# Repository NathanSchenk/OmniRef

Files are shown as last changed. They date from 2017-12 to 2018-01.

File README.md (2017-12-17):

# OmniRef
A universal voltage reference

<br />This work is licensed under a <a rel="license" href="http://creativecommons.org/licenses/by-sa/4.0/">Creative Commons Attribution-ShareAlike 4.0 International License</a>.

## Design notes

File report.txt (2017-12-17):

Plot file 'Z:\Projects\OmniRef\Gerbers\OmniRef-F.Cu.gbr' created.
Plot file 'Z:\Projects\OmniRef\Gerbers\OmniRef-B.Cu.gbr' created.
Plot file 'Z:\Projects\OmniRef\Gerbers\OmniRef-B.Adhes.gbr' created.
Plot file 'Z:\Projects\OmniRef\Gerbers\OmniRef-F.Adhes.gbr' created.
Plot file 'Z:\Projects\OmniRef\Gerbers\OmniRef-B.Paste.gbr' created.
Plot file 'Z:\Projects\OmniRef\Gerbers\OmniRef-F.Paste.gbr' created.
Plot file 'Z:\Projects\OmniRef\Gerbers\OmniRef-B.SilkS.gbr' created.
Plot file 'Z:\Projects\OmniRef\Gerbers\OmniRef-F.SilkS.gbr' created.
Plot file 'Z:\Projects\OmniRef\Gerbers\OmniRef-B.Mask.gbr' created.
Plot file 'Z:\Projects\OmniRef\Gerbers\OmniRef-F.Mask.gbr' created.
Plot file 'Z:\Projects\OmniRef\Gerbers\OmniRef-Cmts.User.gbr' created.
Plot file 'Z:\Projects\OmniRef\Gerbers\OmniRef-Edge.Cuts.gbr' created.
Plot file 'Z:\Projects\OmniRef\Gerbers\OmniRef-Margin.gbr' created.
Plot file 'Z:\Projects\OmniRef\Gerbers\OmniRef-B.CrtYd.gbr' created.
Plot file 'Z:\Projects\OmniRef\Gerbers\OmniRef-F.CrtYd.gbr' created.
Plot file 'Z:\Projects\OmniRef\Gerbers\OmniRef-B.Fab.gbr' created.
Plot file 'Z:\Projects\OmniRef\Gerbers\OmniRef-F.Fab.gbr' created.

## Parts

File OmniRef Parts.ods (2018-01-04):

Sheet: Master Parts List
Reference Designator | Description | Manufacturer | Manufacturer Part | Digi-Key | Cost | Comments
Case | Enclosure | Budd | CU1941 | 377-2068-ND (https://www.digikey.com/product-detail/en/bud-industries/CU-1941/377-2068-ND/439228) | $2.10
BT1 | Battery Snap | Keystone | 81-4 | 36-81-4-ND (https://www.digikey.com/product-detail/en/keystone-electronics/81-4/36-81-4-ND/303952) | $0.71
J1+ | Red Banana Jack | Mueller | BU-00233-2 | 314-1358-ND (https://www.digikey.com/product-detail/en/mueller-electric-co/BU-00233-2/314-1358-ND/2688274) | $1.40 | Gold plated versions available from parts express (https://www.parts-express.com/gold-plated-banana-jack-pair--091-1160)
J1- | Black Banana Jack | Mueller | BU-00233-0 | 314-1357-ND (https://www.digikey.com/product-detail/en/mueller-electric-co/BU-00233-0/314-1357-ND/2688273) | $1.40
J2+ | Red Banana Jack | Mueller | BU-00233-2 | 314-1358-ND (https://www.digikey.com/product-detail/en/mueller-electric-co/BU-00233-2/314-1358-ND/2688274) | $1.40
J2- | Black Banana Jack | Mueller | BU-00233-0 | 314-1357-ND (https://www.digikey.com/product-detail/en/mueller-electric-co/BU-00233-0/314-1357-ND/2688273) | $1.40
SW1 | DPDT Switch | C&K | L202011MS02Q | CKC5100-ND (https://www.digikey.com/product-detail/en/c-k/L202011MS02Q/CKC5100-ND/13853) | $2.94 | Used for battery/external power selection. Also functions as on/off if only one power source is available.
U1 | Series Voltage Reference |  |  |  |  | See "References" page for specific parts
U2 | LDO Regulator | On Semiconductor | LP2951ACDR2G | LP2951ACDR2GOSCT-ND (https://www.digikey.com/product-detail/en/on-semiconductor/LP2951ACDR2G/LP2951ACDR2GOSCT-ND/917952) | $0.65 | LP2951 is the most popular compatable part number, but others will fit. Be sure to get the adjustable version. The A suffix has better regulation.
U3 | Series Voltage Reference |  |  |  |  | Placeholder for DIP footprint reference.
U4 | AP3015 Boost Converter | Diodes Incorporated | AP3015KTR-G1 | AP3015KTR-G1DICT-ND (https://www.digikey.com/product-detail/en/diodes-incorporated/AP3015KTR-G1/AP3015KTR-G1DICT-ND/4505299) | $0.73 | Boost Converter. The AP3015AKTR-G1 is a lower current version that may be a better choice.
Q1 | PNP Transistor | Nexperia | PMBT3906.215 | 1727-2960-1-ND (https://www.digikey.com/product-detail/en/nexperia-usa-inc/PMBT3906215/1727-2960-1-ND/763516) | $0.10 | Drives the "Low Battery" LED
D1 | 1A General Purpose Diode | SMC Diode Solutions | S1MTR | 1655-1506-1-ND (https://www.digikey.com/product-detail/en/smc-diode-solutions/S1MTR/1655-1506-1-ND/6022951) | $0.14 | Input rectifier to protect against reverse polarity connection of external power supply.
D2 | 1A General Purpose Diode | SMC Diode Solutions | S1MTR | 1655-1506-1-ND (https://www.digikey.com/product-detail/en/smc-diode-solutions/S1MTR/1655-1506-1-ND/6022951) | $0.14 | Protects reference IC against being driven by the output terminals.
D3 | 1A General Purpose Diode | SMC Diode Solutions | S1MTR | 1655-1506-1-ND (https://www.digikey.com/product-detail/en/smc-diode-solutions/S1MTR/1655-1506-1-ND/6022951) | $0.14 | Protects first regulator against being driven by the output terminals
D5 | Yellow LED | Kingbright | APTR3216SYCK | 754-1174-1-ND (https://www.digikey.com/product-detail/en/kingbright/APTR3216SYCK/754-1174-1-ND/1747891) | $0.48 | "Low Battery" indication
D6 | 12V Zener Diode | On Semiconductor | 1SMA5927BT3G | 1SMA5927BT3GOSCT-ND (https://www.digikey.com/product-detail/en/on-semiconductor/1SMA5927BT3G/1SMA5927BT3GOSCT-ND/917680) | $0.38 | Protects the reference IC from external voltages applied to the output terminals.
D7 | Green LED | Kingbright | APTR3216CGCK | 754-1167-1-ND (https://www.digikey.com/product-detail/en/kingbright/APTR3216CGCK/754-1167-1-ND/1747884) | $0.39 | "Power On" indication
D8 | 1A Schottky Diode | On Semiconductor | SS14 | SS14CT-ND (https://www.digikey.com/product-detail/en/on-semiconductor/SS14/SS14CT-ND/965729) | $0.41 | Series diode for boost converter
D9 | 1A General Purpose Diode | SMC Diode Solutions | S1MTR | 1655-1506-1-ND (https://www.digikey.com/product-detail/en/smc-diode-solutions/S1MTR/1655-1506-1-ND/6022951) | $0.14 | Protects against reverse polarity from the battery terminals
C1 | 1uF 35v X7R 0805 Ceramic Capacitor | Taiyo Yuden | GMK212B7105KG-T | 587-1438-1-ND (https://www.digikey.com/product-detail/en/taiyo-yuden/GMK212B7105KG-T/587-1438-1-ND/1004069) | $0.14
C2 | 10uF 35v X5R 0805 Ceramic Capacitor | Murata | GRM21BR6YA106ME43L | 490-10515-1-ND (https://www.digikey.com/product-detail/en/murata-electronics-north-america/GRM21BR6YA106ME43L/490-10515-1-ND/5026446) | $0.26
C3 | 1uF 35v X7R 0805 Ceramic Capacitor | Taiyo Yuden | GMK212B7105KG-T | 587-1438-1-ND (https://www.digikey.com/product-detail/en/taiyo-yuden/GMK212B7105KG-T/587-1438-1-ND/1004069) | $0.14 | This part improves stability and reduces noise on the linear regulator.
C4 | 1uF 35v X7R 0805 Ceramic Capacitor | Taiyo Yuden | GMK212B7105KG-T | 587-1438-1-ND (https://www.digikey.com/product-detail/en/taiyo-yuden/GMK212B7105KG-T/587-1438-1-ND/1004069) | $0.14
C5 | 1uF 35v X7R 0805 Ceramic Capacitor | Taiyo Yuden | GMK212B7105KG-T | 587-1438-1-ND (https://www.digikey.com/product-detail/en/taiyo-yuden/GMK212B7105KG-T/587-1438-1-ND/1004069) | $0.14
C6 | 10uF 35v X5R 0805 Ceramic Capacitor | Murata | GRM21BR6YA106ME43L | 490-10515-1-ND (https://www.digikey.com/product-detail/en/murata-electronics-north-america/GRM21BR6YA106ME43L/490-10515-1-ND/5026446) | $0.26 | Main bypass capacitor for the linear regulator
C7 | 10uF 35v X5R 0805 Ceramic Capacitor | Murata | GRM21BR6YA106ME43L | 490-10515-1-ND (https://www.digikey.com/product-detail/en/murata-electronics-north-america/GRM21BR6YA106ME43L/490-10515-1-ND/5026446) | $0.26
C8 | 10uF 35v X5R 0805 Ceramic Capacitor | Murata | GRM21BR6YA106ME43L | 490-10515-1-ND (https://www.digikey.com/product-detail/en/murata-electronics-north-america/GRM21BR6YA106ME43L/490-10515-1-ND/5026446) | $0.26
C9 | 10uF 6032 25V Tantalum Capacitor |  | T491C106K035AT | 399-8333-1-ND (https://www.digikey.com/product-detail/en/kemet/T491C106K035AT/399-8333-1-ND/3472056) | $0.62
C10 | 1uF 35v X7R 0805 Ceramic Capacitor | Taiyo Yuden | GMK212B7105KG-T | 587-1438-1-ND (https://www.digikey.com/product-detail/en/taiyo-yuden/GMK212B7105KG-T/587-1438-1-ND/1004069) | $0.14 | Reduces noise on certain Maxim references
C11 | 10uF 35v X5R 0805 Ceramic Capacitor | Murata | GRM21BR6YA106ME43L | 490-10515-1-ND (https://www.digikey.com/product-detail/en/murata-electronics-north-america/GRM21BR6YA106ME43L/490-10515-1-ND/5026446) | $0.26 | Input bypass capacitor for the boost converter
C12 | 10pF 50V NP0 Ceramic Capacitor |  |  |  | $0.10 | Stabilizing capacitor for the boost converter
C13 | 10uF 35v X5R 0805 Ceramic Capacitor | Murata | GRM21BR6YA106ME43L | 490-10515-1-ND (https://www.digikey.com/product-detail/en/murata-electronics-north-america/GRM21BR6YA106ME43L/490-10515-1-ND/5026446) | $0.26 | Output bypass capacitor for the boost converter
RV1 | 10K SMD Trimmer 3324W | Bourns | 3224W-1-103E | 3224W-103ECT-ND (https://www.digikey.com/product-detail/en/bourns-inc/3224W-1-103E/3224W-103ECT-ND/225672) | $4.92 | Only used for references with trim terminal. See "References" page for specific parts.
R1 | 0805 Resistor |  |  |  | $0.10 | Part of linear regulator voltage setting network. See "Linear Regulator" page for details
R2 | High Stability 0805 Resistor |  |  |  | $0.10 | Only used for references with trim terminal. This needs to be a high stability part. See "References" page for details.
R3 | 0805 Resistor |  |  |  | $0.10 | Part of linear regulator voltage setting network. See "Linear Regulator" page for details
R4 | 1 Ohm 0805 Resistor |  |  |  | $0.10 | This increases the ESR of the bypass capacitor on the linear regulator. Helps keep LDO from oscillating.
R5 | 100K 0805 Resistor |  |  |  | $0.10 | Bias resistor for Q1. 100K is the minimum value allowed by the LDO error terminal.
R6 | 1 Ohm 0805 Resistor |  |  |  | $0.10 | This increases the ESR of the bypass capacitor on the voltage reference. Helps prevent oscillatons.
R7 | 1K 0805 Resistor |  |  |  | $0.10 | Dropping resistor for "Low Battery" LED
R8 | 10K 0805 Resistor |  |  |  | $0.10 | Output resistor. Used to keep the reference IC biased in quadrant I. Not necessary if RV1 is used.
R9 | 0 Ohm 0805 Resistor |  |  |  | $0.10 | Only used for certain references. See "References" page to determine if needed.
R10 | 1K 0805 Resistor |  |  |  | $0.10 | Dropping resistor for "Power On" LED
R11 | 0 Ohm 0805 Resistor |  |  |  | $0.10 | Jumper to be used if the boost converter is not used.
R12 | 1M 0805 Resistor |  |  |  | $0.10 | Voltage setting resistor for the boost converter
R13 | 82K 0805 Resistor |  |  |  | $0.10 | Voltage setting resistor for the boost converter
R14 | High Stability 0805 Resistor |  |  |  | $0.10 | Used only for references with the "trim" terminal. "Expands the scale" of RV1
R15 | High Stability 0805 Resistor |  |  |  | $0.10 | Used only for references with the "trim" terminal. "Expands the scale" of RV1
L1 | 10uH Inductor | Taiyo Yuden | NR6028T100M | 587-2102-1-ND (https://www.digikey.com/product-detail/en/taiyo-yuden/NR6028T100M/587-2102-1-ND/1866242) | $0.32 | Inductor for the boost converter

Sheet: Linear Regulator
Primary Voltage Regulators:
SOIC Pinout | LP2954 | LP4951C | LP2951 | NCV2951
1 | OUT | OUTPUT | OUTPUT | OUTPUT
2 | SENSE | SENSE | SENSE | SENSE
3 | /SHUTDOWN | SHUTDOWN | SHUTDOWN | SHUTDOWN
4 | GROUND | GROUND | GND | GND
5 | /ERROR | /ERROR | /ERROR | /ERROR
6 | 5V TAP | V TAP | V TAP | V TAP
7 | FEEDBACK | FEEDBACK | FEEDBACK | FEEDBACK
8 | INPUT | INPUT | INPUT | INPUT
Resistor Selection: |  |  | LED | LED
Output Voltage | R3 | R1 | R7 | R10
13.58 | 100K | 10K | 3.9K | 3.9K
6.85 | 100K | 22K | 1.5K | 1.5K
4.98 | 100K | 33K | 1K | 1K

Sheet: Resistor Calc
AP3015 Resistor Calculator
R12 | 1000000 | Vout | 16.230
R13 | 82000
LP2951 Resistor Calculator
R3 | 100000 | Vout | 4.975
R1 | 33000
LED Resistor Calculator
R7 | 991.81 | I_LED | 0.003
R10 | 991.81 | I_LED | 0.003

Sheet: References
Part # | Package | Voltage | R9 | C10 | C4 | C5 | R2 | RV1 | R14 | R15
Texas Instruments
REF102CU | SO | 10.000 | No-Pop | No-Pop | 1uF | No-Pop | 1M | 20K | 1 | 1
REF102CP | PDIP | 10.000 | No-Pop | No-Pop | 1uF | No-Pop | 1M | 20K | 1 | 1
REF5010ID | SO | 10.000 | No-Pop | No-Pop | No-Pop | 1uF | 470K | 10K | 1 | 1
Analog Devices
ADR4550ARZ | SO | 5.000 | No-Pop | No-Pop | No-Pop | No-Pop | No-Pop | No-Pop | No-Pop | No-Pop
ADR4550BRZ | SO | 5.000 | No-Pop | No-Pop | No-Pop | No-Pop | No-Pop | No-Pop | No-Pop | No-Pop
ADR4530BRZ | SO | 3.000 | No-Pop | No-Pop | No-Pop | No-Pop | No-Pop | No-Pop | No-Pop | No-Pop
ADR4525BRZ | SO | 2.500 | No-Pop | No-Pop | No-Pop | No-Pop | No-Pop | No-Pop | No-Pop | No-Pop
AD587KRZ | SO | 10.000 | No-Pop | No-Pop | 1uF | No-Pop | 1 | 10K | 10K? | 10K?
AD587UQ | CDIP | 10.000 | No-Pop | No-Pop | 1uF | No-Pop | 1 | 10K | 10K? | 10K?
Maxim Integrated
MAX6325CPA | PDIP | 2.500 | No-Pop | 1uF | No-Pop | No-Pop | 1 | 10K | 1 | 1
MAX6325CSA | SO | 2.500 | No-Pop | 1uF | No-Pop | No-Pop | 1 | 10K | 1 | 1
MAX6325MJA | CDIP | 2.500 | No-Pop | 1uF | No-Pop | No-Pop | 1 | 10K | 1 | 1
MAX6341CPA | PDIP | 4.096 | No-Pop | 1uF | No-Pop | No-Pop | 1 | 10K | 1 | 1
MAX6341CSA | SO | 4.096 | No-Pop | 1uF | No-Pop | No-Pop | 1 | 10K | 1 | 1
MAX6341MJA | CDIP | 4.096 | No-Pop | 1uF | No-Pop | No-Pop | 1 | 10K | 1 | 1
MAX6350CPA | PDIP | 5.000 | No-Pop | 1uF | No-Pop | No-Pop | 1 | 10K | 1 | 1
MAX6350CSA | SO | 5.000 | No-Pop | 1uF | No-Pop | No-Pop | 1 | 10K | 1 | 1
MAX6350MJA | CDIP | 5.000 | No-Pop | 1uF | No-Pop | No-Pop | 1 | 10K | 1 | 1
REF01 |  | 10.000 | No-Pop | No-Pop | No-Pop | No-Pop | 1 | 10K | 1 | 1
REF02 |  | 5.000 | No-Pop | No-Pop | No-Pop | No-Pop | 1 | 10K | 1 | 1
Apex
VRE302 |  | 2.500
VRE3025 |  | 2.500
VRE304 |  | 4.500
VRE305 |  | 5.000
VRE3050 |  | 5.000
VRE306 |  | 6.000
VRE310 |  | 10.000
Intersil
ISL21090BFB812Z-TK | SO | 1.250 | No-Pop
ISL21090BFB825Z-TK | SO | 2.500 | No-Pop
ISL21090BFB850Z-TK | SO | 5.000 | No-Pop
ISL21090BFB875Z-TK | SO | 7.500 | No-Pop
Linear Technology
LT1236 |  |  | No-Pop | No-Pop | No-Pop
LT1027 | PDIP ONLY
LT1019

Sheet: AD587KRZ BOM
Reference Designator | Qty | Description | Manufacturer | Manufacturer Part | Digi-Key | Cost | Ext Cost
PCB | 1 | Printed Circuit Board | Schenktronics | OmniRef-PCB |  | $5.00 | $5.00
Enclosure Plastic Parts | 1 | Laser Cut Plastic Parts | Schenktronics | OmniRef-Acrylic |  | $10.00 | $10.00
Case | 1 | Enclosure | Budd | CU1941 | 377-2068-ND (https://www.digikey.com/product-detail/en/bud-industries/CU-1941/377-2068-ND/439228) | $2.10 | $2.10
BT1 | 1 | Battery Snap | Keystone | 81-4 | 36-81-4-ND (https://www.digikey.com/product-detail/en/keystone-electronics/81-4/36-81-4-ND/303952) | $0.71 | $0.71
J1+, J2+ | 2 | Red Banana Jack | Mueller | BU-00233-2 | 314-1358-ND (https://www.digikey.com/product-detail/en/mueller-electric-co/BU-00233-2/314-1358-ND/2688274) | $1.40 | $2.80
J1-, J2- | 2 | Black Banana Jack | Mueller | BU-00233-0 | 314-1357-ND (https://www.digikey.com/product-detail/en/mueller-electric-co/BU-00233-0/314-1357-ND/2688273) | $1.40 | $2.80
SW1 | 1 | DPDT Switch | C&K | L202011MS02Q | CKC5100-ND (https://www.digikey.com/product-detail/en/c-k/L202011MS02Q/CKC5100-ND/13853) | $2.94 | $2.94
U1 | 1 | Series Voltage Reference | Analog Devices | AD587KRZ | AD587KRZ-ND (https://www.digikey.com/product-detail/en/analog-devices-inc/AD587KRZ/AD587KRZ-ND/936637) | $8.44 | $8.44
U2 | 1 | LDO Regulator | On Semiconductor | LP2951ACDR2G | LP2951ACDR2GOSCT-ND (https://www.digikey.com/product-detail/en/on-semiconductor/LP2951ACDR2G/LP2951ACDR2GOSCT-ND/917952) | $0.65 | $0.65
U4 | 1 | AP3015 Boost Converter | Diodes Incorporated | AP3015KTR-G1 | AP3015KTR-G1DICT-ND (https://www.digikey.com/product-detail/en/diodes-incorporated/AP3015KTR-G1/AP3015KTR-G1DICT-ND/4505299) | $0.73 | $0.73
Q1 | 1 | PNP Transistor | Nexperia | PMBT3906.215 | 1727-2960-1-ND (https://www.digikey.com/product-detail/en/nexperia-usa-inc/PMBT3906215/1727-2960-1-ND/763516) | $0.10 | $0.10
D1, D2, D3, D9 | 4 | 1A General Purpose Diode | SMC Diode Solutions | S1MTR | 1655-1506-1-ND (https://www.digikey.com/product-detail/en/smc-diode-solutions/S1MTR/1655-1506-1-ND/6022951) | $0.14 | $0.56
D5 | 1 | Yellow LED | Kingbright | APTR3216SYCK | 754-1174-1-ND (https://www.digikey.com/product-detail/en/kingbright/APTR3216SYCK/754-1174-1-ND/1747891) | $0.48 | $0.48
D6 | 1 | 12V Zener Diode | On Semiconductor | 1SMA5927BT3G | 1SMA5927BT3GOSCT-ND (https://www.digikey.com/product-detail/en/on-semiconductor/1SMA5927BT3G/1SMA5927BT3GOSCT-ND/917680) | $0.38 | $0.38
D7 | 1 | Green LED | Kingbright | APTR3216CGCK | 754-1167-1-ND (https://www.digikey.com/product-detail/en/kingbright/APTR3216CGCK/754-1167-1-ND/1747884) | $0.39 | $0.39
D8 | 1 | 1A Schottky Diode | On Semiconductor | SS14 | SS14CT-ND (https://www.digikey.com/product-detail/en/on-semiconductor/SS14/SS14CT-ND/965729) | $0.41 | $0.41
C1, C3, C4 | 3 | 1uF 35v X7R 0805 Ceramic Capacitor | Taiyo Yuden | GMK212B7105KG-T | 587-1438-1-ND (https://www.digikey.com/product-detail/en/taiyo-yuden/GMK212B7105KG-T/587-1438-1-ND/1004069) | $0.14 | $0.41
C2, C6, C7, C11, C13 | 5 | 10uF 35v X5R 0805 Ceramic Capacitor | Murata | GRM21BR6YA106ME43L | 490-10515-1-ND (https://www.digikey.com/product-detail/en/murata-electronics-north-america/GRM21BR6YA106ME43L/490-10515-1-ND/5026446) | $0.26 | $1.32
C12 | 1 | 10pF 50V NP0 Ceramic Capacitor | Any | Any NP0 50V | 709-1168-1-ND (https://www.digikey.com/product-detail/en/johanson-dielectrics-inc/500R15N100JV4T/709-1168-1-ND/1859500) | $0.10 | $0.10
RV1 | 1 | 10K SMD Trimmer 3324W | Bourns | 3224W-1-103E | 3224W-103ECT-ND (https://www.digikey.com/product-detail/en/bourns-inc/3224W-1-103E/3224W-103ECT-ND/225672) | $4.92 | $4.92
R1, R14, R15 | 3 | 10K 0805 Resistor | Any | Any 1% | 311-10.0KCRCT-ND (https://www.digikey.com/product-detail/en/yageo/RC0805FR-0710KL/311-10.0KCRCT-ND/730482) | $0.10 | $0.30
R2, R4, R6 | 3 | 1 Ohm 0805 Resistor | Any | Any 1% | 311-1.00CRCT-ND (https://www.digikey.com/product-detail/en/yageo/RC0805FR-071RL/311-1.00CRCT-ND/730390) | $0.10 | $0.30
R3, R5 | 2 | 100K 0805 Resistor | Any | Any 1% | 311-100KCRCT-ND (https://www.digikey.com/product-detail/en/yageo/RC0805FR-07100KL/311-100KCRCT-ND/730491) | $0.10 | $0.20
R7, R10 | 2 | 3.9K 0805 Resistor | Any | Any 1% | 311-3.90KCRCT-ND (https://www.digikey.com/product-detail/en/yageo/RC0805FR-073K9L/311-3.90KCRCT-ND/730785) | $0.10 | $0.20
R12 | 1 | 1M 0805 Resistor | Any | Any 1% | 311-1.00MCRCT-ND (https://www.digikey.com/product-detail/en/yageo/RC0805FR-071ML/311-1.00MCRCT-ND/730392) | $0.10 | $0.10
R13 | 1 | 82K 0805 Resistor | Any | Any 1% | 311-82.0KCRCT-ND (https://www.digikey.com/product-detail/en/yageo/RC0805FR-0782KL/311-82.0KCRCT-ND/731112) | $0.10 | $0.10
L1 | 1 | 10uH Inductor | Taiyo Yuden | NR6028T100M | 587-2102-1-ND (https://www.digikey.com/product-detail/en/taiyo-yuden/NR6028T100M/587-2102-1-ND/1866242) | $0.32 | $0.32
 | 44 |  |  |  |  |  | $46.76 | Total
U3, C5, C8, C9, C10, R8, R9, R11 | NO-POP

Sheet: AD587KRZ PCB Assy
Reference Designator | Qty | Description | Manufacturer | Manufacturer Part | Digi-Key | Cost | Ext Cost
U1 | 1 | Series Voltage Reference | Analog Devices | AD587KRZ | AD587KRZ-ND (https://www.digikey.com/product-detail/en/analog-devices-inc/AD587KRZ/AD587KRZ-ND/936637) | $8.44 | $8.44
U2 | 1 | LDO Regulator | On Semiconductor | LP2951ACDR2G | LP2951ACDR2GOSCT-ND (https://www.digikey.com/product-detail/en/on-semiconductor/LP2951ACDR2G/LP2951ACDR2GOSCT-ND/917952) | $0.65 | $0.65
U4 | 1 | AP3015 Boost Converter | Diodes Incorporated | AP3015KTR-G1 | AP3015KTR-G1DICT-ND (https://www.digikey.com/product-detail/en/diodes-incorporated/AP3015KTR-G1/AP3015KTR-G1DICT-ND/4505299) | $0.73 | $0.73
Q1 | 1 | PNP Transistor | Nexperia | PMBT3906.215 | 1727-2960-1-ND (https://www.digikey.com/product-detail/en/nexperia-usa-inc/PMBT3906215/1727-2960-1-ND/763516) | $0.10 | $0.10
D1, D2, D3, D9 | 4 | 1A General Purpose Diode | SMC Diode Solutions | S1MTR | 1655-1506-1-ND (https://www.digikey.com/product-detail/en/smc-diode-solutions/S1MTR/1655-1506-1-ND/6022951) | $0.14 | $0.56
D5 | 1 | Yellow LED Reverse Mount | Kingbright | APTR3216SYCK | 754-1174-1-ND (https://www.digikey.com/product-detail/en/kingbright/APTR3216SYCK/754-1174-1-ND/1747891) | $0.48 | $0.48
D6 | 1 | 12V Zener Diode | On Semiconductor | 1SMA5927BT3G | 1SMA5927BT3GOSCT-ND (https://www.digikey.com/product-detail/en/on-semiconductor/1SMA5927BT3G/1SMA5927BT3GOSCT-ND/917680) | $0.38 | $0.38
D7 | 1 | Green LED Reverse Mount | Kingbright | APTR3216CGCK | 754-1167-1-ND (https://www.digikey.com/product-detail/en/kingbright/APTR3216CGCK/754-1167-1-ND/1747884) | $0.39 | $0.39
D8 | 1 | 1A Schottky Diode | On Semiconductor | SS14 | SS14CT-ND (https://www.digikey.com/product-detail/en/on-semiconductor/SS14/SS14CT-ND/965729) | $0.41 | $0.41
C1, C3, C4 | 3 | 1uF 50v X7R 0805 Ceramic Capacitor | C28323 | CL21B105KBFNNNE |  | $0.00 | $0.00
C2, C6, C7, C11, C13 | 5 | 22uF 25v X5R 0805 Ceramic Capacitor | C45783 | CL21A226MAQNNNE |  | $0.00 | $0.00
C12 | 1 | 10pF 50V NP0 Ceramic Capacitor | C1785 | CL21C100JBANNNC |  | $0.00 | $0.00
RV1 | 1 | 10K SMD Trimmer 3324W | Any | 3224W-1-103E | 3224W-103ECT-ND (https://www.digikey.com/product-detail/en/bourns-inc/3224W-1-103E/3224W-103ECT-ND/225672) | $4.92 | $4.92
R1, R14, R15 | 3 | 10K 0805 Resistor | C17414 | 0805W8F1002T5E |  | $0.00 | $0.00
R2, R4, R6 | 3 | 1 Ohm 0805 Resistor | C25271 | 0805W8F100KT5E |  | $0.00 | $0.00
R3, R5 | 2 | 100K 0805 Resistor | C17407 | 0805W8F1003T5E |  | $0.00 | $0.00
R7, R10 | 2 | 3.9K 0805 Resistor | C17614 | 0805W8F3901T5E |  | $0.00 | $0.00
R12 | 1 | 1M 0805 Resistor | C17514 | 0805W8F1004T5E |  | $0.00 | $0.00
R13 | 1 | 82K 0805 Resistor | C17840 | 0805W8F8202T5E |  | $0.00 | $0.00
L1 | 1 | 10uH Inductor | Taiyo Yuden | NR6028T100M | 587-2102-1-ND (https://www.digikey.com/product-detail/en/taiyo-yuden/NR6028T100M/587-2102-1-ND/1866242) | $0.32 | $0.32
 | 35 |  |  |  |  |  | $17.38 | Total
U3, C5, C8, C9, C10, R8, R9, R11 | NO-POP

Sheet: ADR4550BRZ BOM
Reference Designator | Qty | Description | Manufacturer | Manufacturer Part | Digi-Key | Cost | Ext Cost
PCB | 1 | Printed Circuit Board | Schenktronics | OmniRef-PCB |  | $5.00 | $5.00
Enclosure Plastic Parts | 1 | Laser Cut Plastic Parts | Schenktronics | OmniRef-Acrylic |  | $10.00 | $10.00
Case | 1 | Enclosure | Budd | CU1941 | 377-2068-ND (https://www.digikey.com/product-detail/en/bud-industries/CU-1941/377-2068-ND/439228) | $2.10 | $2.10
BT1 | 1 | Battery Snap | Keystone | 81-4 | 36-81-4-ND (https://www.digikey.com/product-detail/en/keystone-electronics/81-4/36-81-4-ND/303952) | $0.71 | $0.71
J1+, J2+ | 2 | Red Banana Jack | Mueller | BU-00233-2 | 314-1358-ND (https://www.digikey.com/product-detail/en/mueller-electric-co/BU-00233-2/314-1358-ND/2688274) | $1.40 | $2.80
J1-, J2- | 2 | Black Banana Jack | Mueller | BU-00233-0 | 314-1357-ND (https://www.digikey.com/product-detail/en/mueller-electric-co/BU-00233-0/314-1357-ND/2688273) | $1.40 | $2.80
SW1 | 1 | DPDT Switch | C&K | L202011MS02Q | CKC5100-ND (https://www.digikey.com/product-detail/en/c-k/L202011MS02Q/CKC5100-ND/13853) | $2.94 | $2.94
U1 | 1 | Series Voltage Reference | Analog Devices | ADR4550BRZ | ADR4550BRZ-R7CT-ND (https://www.digikey.com/product-detail/en/analog-devices-inc/ADR4550BRZ-R7/ADR4550BRZ-R7CT-ND/4909197) | $8.54 | $8.54
U2 | 1 | LDO Regulator | On Semiconductor | LP2951ACDR2G | LP2951ACDR2GOSCT-ND (https://www.digikey.com/product-detail/en/on-semiconductor/LP2951ACDR2G/LP2951ACDR2GOSCT-ND/917952) | $0.65 | $0.65
Q1 | 1 | PNP Transistor | Nexperia | PMBT3906.215 | 1727-2960-1-ND (https://www.digikey.com/product-detail/en/nexperia-usa-inc/PMBT3906215/1727-2960-1-ND/763516) | $0.10 | $0.10
D1, D2, D3, D9 | 4 | 1A General Purpose Diode | SMC Diode Solutions | S1MTR | 1655-1506-1-ND (https://www.digikey.com/product-detail/en/smc-diode-solutions/S1MTR/1655-1506-1-ND/6022951) | $0.14 | $0.56
D5 | 1 | Yellow LED | Kingbright | APTR3216SYCK | 754-1174-1-ND (https://www.digikey.com/product-detail/en/kingbright/APTR3216SYCK/754-1174-1-ND/1747891) | $0.48 | $0.48
D6 | 1 | 12V Zener Diode | On Semiconductor | 1SMA5927BT3G | 1SMA5927BT3GOSCT-ND (https://www.digikey.com/product-detail/en/on-semiconductor/1SMA5927BT3G/1SMA5927BT3GOSCT-ND/917680) | $0.38 | $0.38
D7 | 1 | Green LED | Kingbright | APTR3216CGCK | 754-1167-1-ND (https://www.digikey.com/product-detail/en/kingbright/APTR3216CGCK/754-1167-1-ND/1747884) | $0.39 | $0.39
C1, C3 | 2 | 1uF 35v X7R 0805 Ceramic Capacitor | Taiyo Yuden | GMK212B7105KG-T | 587-1438-1-ND (https://www.digikey.com/product-detail/en/taiyo-yuden/GMK212B7105KG-T/587-1438-1-ND/1004069) | $0.14 | $0.28
C2, C6, C7 | 3 | 10uF 35v X5R 0805 Ceramic Capacitor | Murata | GRM21BR6YA106ME43L | 490-10515-1-ND (https://www.digikey.com/product-detail/en/murata-electronics-north-america/GRM21BR6YA106ME43L/490-10515-1-ND/5026446) | $0.26 | $0.79
R1 | 1 | 10K 0805 Resistor | Any | Any 1% | 311-10.0KCRCT-ND (https://www.digikey.com/product-detail/en/yageo/RC0805FR-0710KL/311-10.0KCRCT-ND/730482) | $0.10 | $0.10
R4, R6 | 2 | 1 Ohm 0805 Resistor | Any | Any 1% | 311-1.00CRCT-ND (https://www.digikey.com/product-detail/en/yageo/RC0805FR-071RL/311-1.00CRCT-ND/730390) | $0.10 | $0.20
R3, R5 | 2 | 100K 0805 Resistor | Any | Any 1% | 311-100KCRCT-ND (https://www.digikey.com/product-detail/en/yageo/RC0805FR-07100KL/311-100KCRCT-ND/730491) | $0.10 | $0.20
R7, R10 | 2 | 1.5K 0805 Resistor | Any | Any 1% | 311-1.50KCRCT-ND (https://www.digikey.com/product-detail/en/yageo/RC0805FR-071K5L/311-1.50KCRCT-ND/730443) | $0.10 | $0.20
R11 | 1 | 0 Ohm 0805 Resistor | Any | Any |  | $0.10 | $0.10
 | 32 |  |  |  |  |  | $39.32 | Total
U3, U4, C4, C5, C8, C9, C10, C11, C12, C13, R2, R8, R9, R12, R13, R14, R15, RV1, D8, L1 | NO-POP

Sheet: ADR4550BRZ PCB Assy
Reference Designator | Qty | Description | Manufacturer | Manufacturer Part | Digi-Key | Cost | Ext Cost
U1 | 1 | Series Voltage Reference | Analog Devices | ADR4550BRZ | ADR4550BRZ-R7CT-ND (https://www.digikey.com/product-detail/en/analog-devices-inc/ADR4550BRZ-R7/ADR4550BRZ-R7CT-ND/4909197) | $8.54 | $8.54
U2 | 1 | LDO Regulator | On Semiconductor | LP2951ACDR2G | LP2951ACDR2GOSCT-ND (https://www.digikey.com/product-detail/en/on-semiconductor/LP2951ACDR2G/LP2951ACDR2GOSCT-ND/917952) | $0.65 | $0.65
Q1 | 1 | PNP Transistor | Nexperia | PMBT3906.215 | 1727-2960-1-ND (https://www.digikey.com/product-detail/en/nexperia-usa-inc/PMBT3906215/1727-2960-1-ND/763516) | $0.10 | $0.10
D1, D2, D3, D9 | 4 | 1A General Purpose Diode | SMC Diode Solutions | S1MTR | 1655-1506-1-ND (https://www.digikey.com/product-detail/en/smc-diode-solutions/S1MTR/1655-1506-1-ND/6022951) | $0.14 | $0.56
D5 | 1 | Yellow LED | Kingbright | APTR3216SYCK | 754-1174-1-ND (https://www.digikey.com/product-detail/en/kingbright/APTR3216SYCK/754-1174-1-ND/1747891) | $0.48 | $0.48
D6 | 1 | 12V Zener Diode | On Semiconductor | 1SMA5927BT3G | 1SMA5927BT3GOSCT-ND (https://www.digikey.com/product-detail/en/on-semiconductor/1SMA5927BT3G/1SMA5927BT3GOSCT-ND/917680) | $0.38 | $0.38
D7 | 1 | Green LED | Kingbright | APTR3216CGCK | 754-1167-1-ND (https://www.digikey.com/product-detail/en/kingbright/APTR3216CGCK/754-1167-1-ND/1747884) | $0.39 | $0.39
C1, C3 | 2 | 1uF 50v X7R 0805 Ceramic Capacitor | C28323 | CL21B105KBFNNNE |  | $0.00 | $0.00
C2, C6, C7 | 3 | 22uF 25v X5R 0805 Ceramic Capacitor | C45783 | CL21A226MAQNNNE |  | $0.00 | $0.00
R1 | 1 | 10K 0805 Resistor | C17414 | 0805W8F1002T5E |  | $0.00 | $0.00
R4, R6 | 2 | 1 Ohm 0805 Resistor | C25271 | 0805W8F100KT5E |  | $0.00 | $0.00
R3, R5 | 2 | 100K 0805 Resistor | C17407 | 0805W8F1003T5E |  | $0.00 | $0.00
R7, R10 | 2 | 1.5K 0805 Resistor | C4310 | 0805 F1501T5E |  | $0.10 | $0.20
R11 | 1 | 0 Ohm 0805 Resistor | C17477 | 0805 F0000T5E |  | $0.10 | $0.10
 | 23 |  |  |  |  |  | $11.40 | Total
U3, U4, C4, C5, C8, C9, C10, C11, C12, C13, R2, R8, R9, R12, R13, R14, R15, RV1, D8, L1 | NO-POP

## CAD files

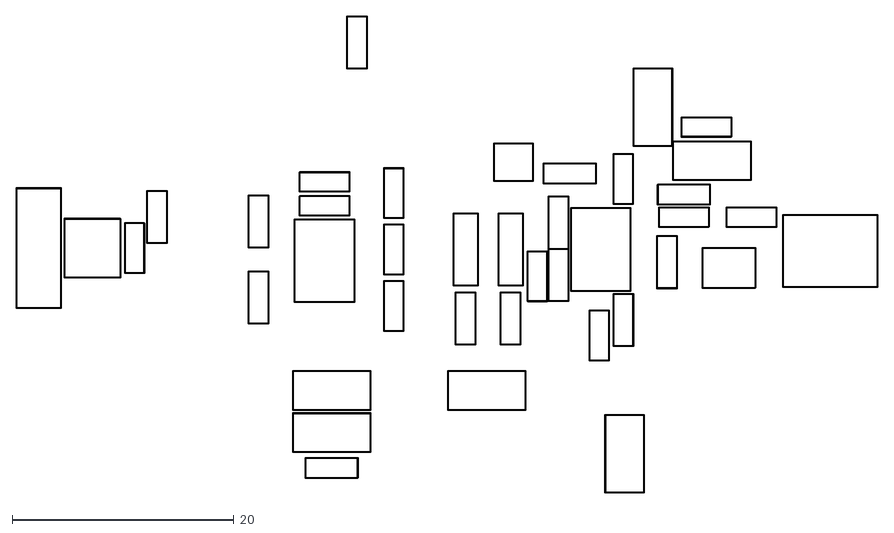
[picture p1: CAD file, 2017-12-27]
Mechanical/OmniRef-B.CrtYd.dxf
77.7 x 43.0

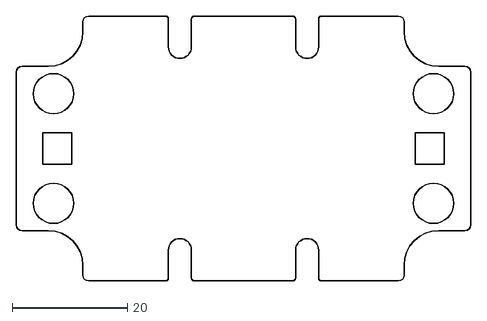
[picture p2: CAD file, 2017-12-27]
Mechanical/OmniRefInsulator.dxf
79.0 x 46.0

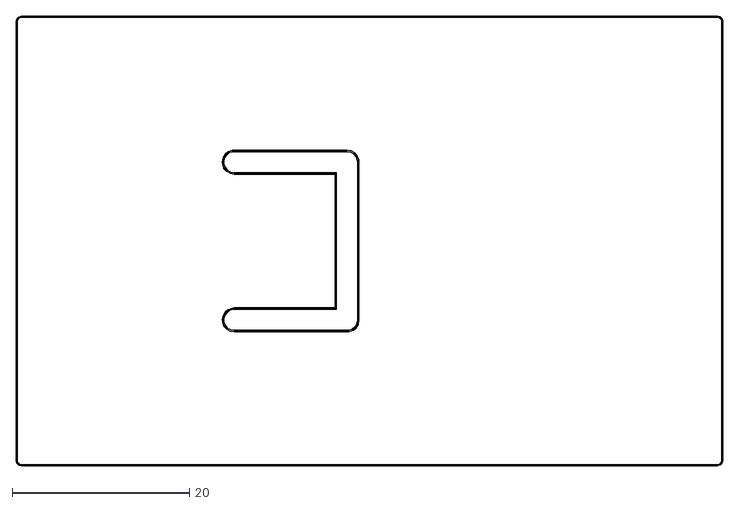
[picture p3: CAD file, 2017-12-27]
Mechanical/OmniRef-Edge.Cuts.dxf
79.6 x 50.6

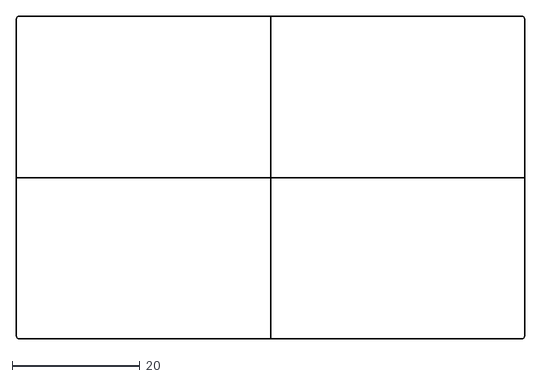
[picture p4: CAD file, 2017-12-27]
Mechanical/OmniRefOutline.dxf
79.5 x 50.5

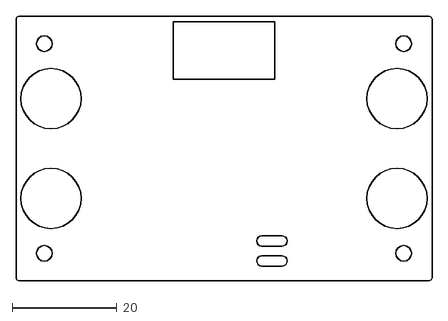
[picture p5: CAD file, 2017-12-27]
Mechanical/OmniRefTopCover_SMD.dxf
79.4 x 50.4

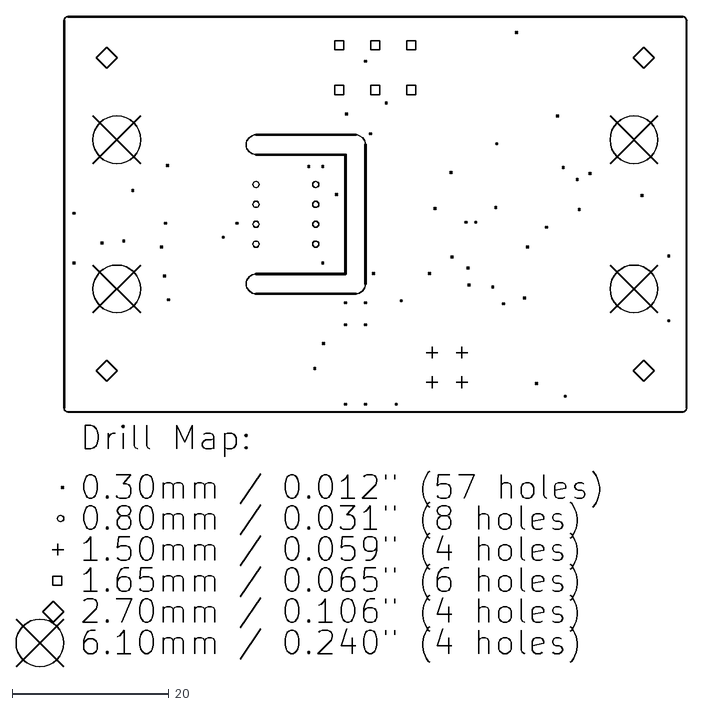
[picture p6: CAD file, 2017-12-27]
Mechanical/OmniRef-drl_map.dxf
85.7 x 83.1

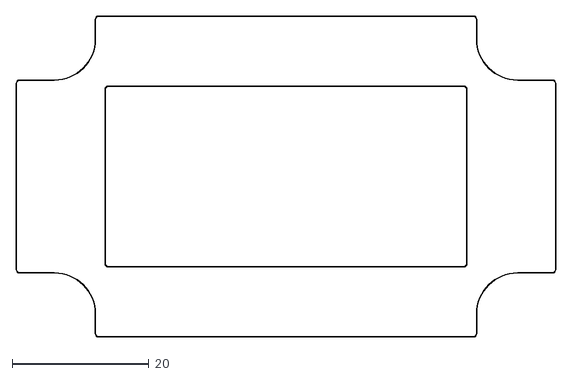
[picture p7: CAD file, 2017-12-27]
Mechanical/OmniRef9vGuide.dxf
79.0 x 47.0

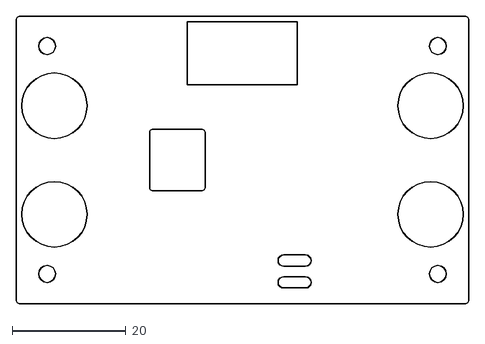
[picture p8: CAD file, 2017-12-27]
Mechanical/OmniRefTopCover_DIP.dxf
79.4 x 50.4

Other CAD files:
Mechanical/hb1941.dwg

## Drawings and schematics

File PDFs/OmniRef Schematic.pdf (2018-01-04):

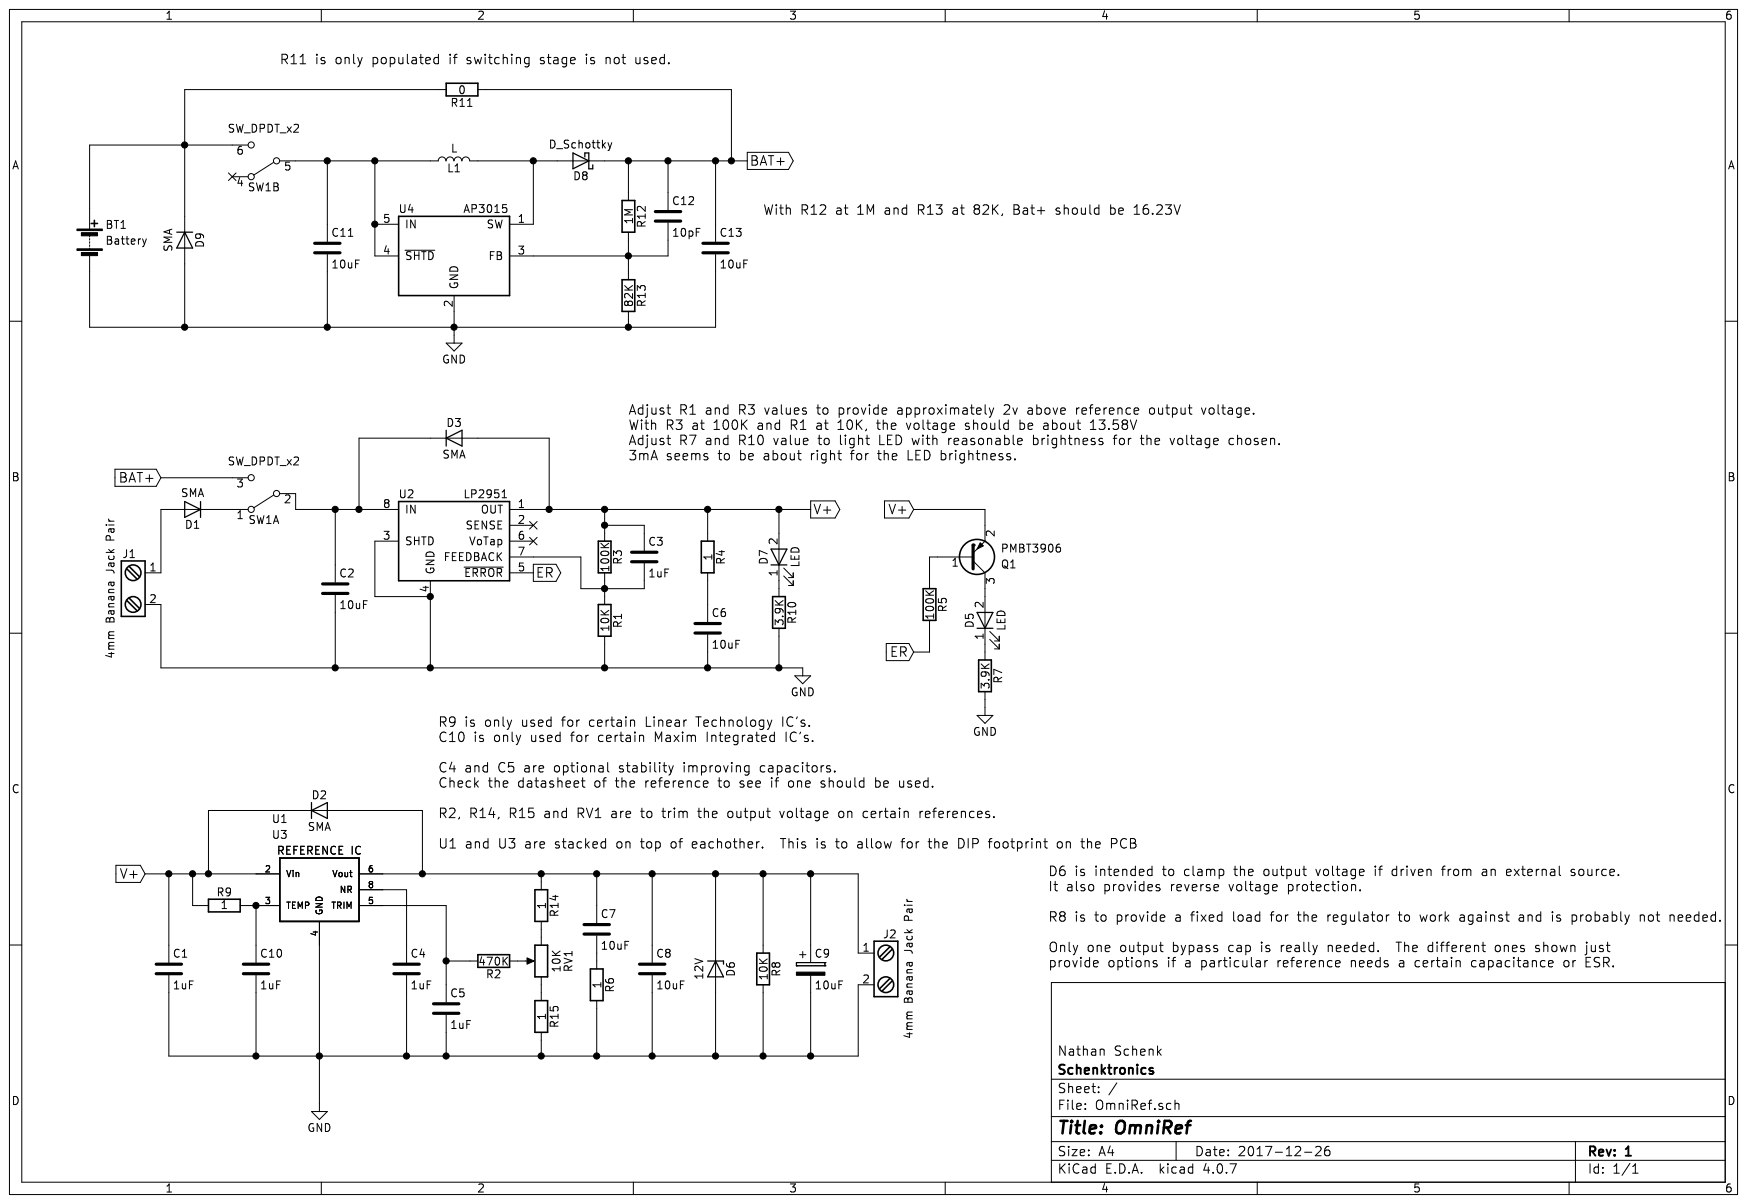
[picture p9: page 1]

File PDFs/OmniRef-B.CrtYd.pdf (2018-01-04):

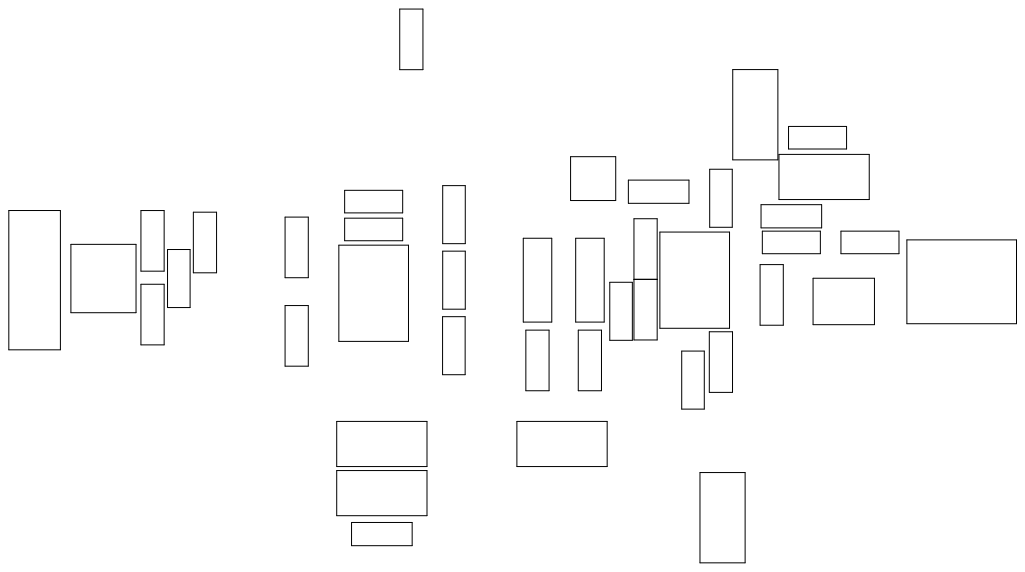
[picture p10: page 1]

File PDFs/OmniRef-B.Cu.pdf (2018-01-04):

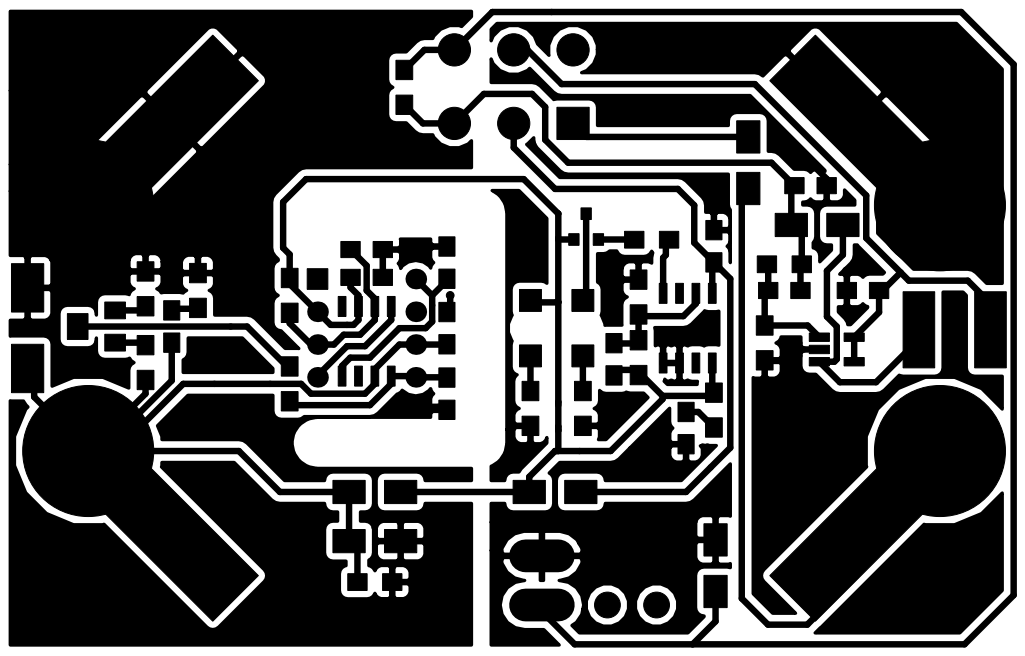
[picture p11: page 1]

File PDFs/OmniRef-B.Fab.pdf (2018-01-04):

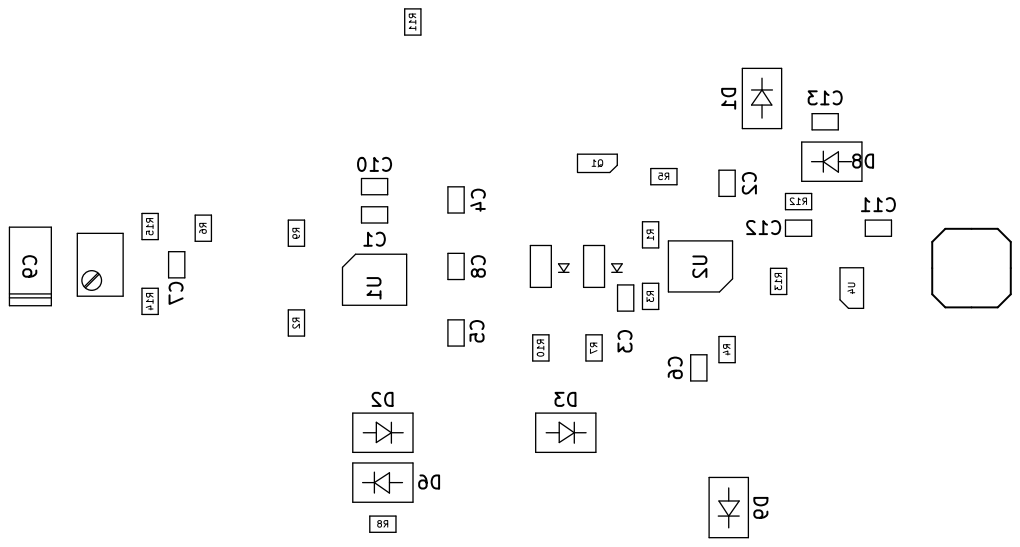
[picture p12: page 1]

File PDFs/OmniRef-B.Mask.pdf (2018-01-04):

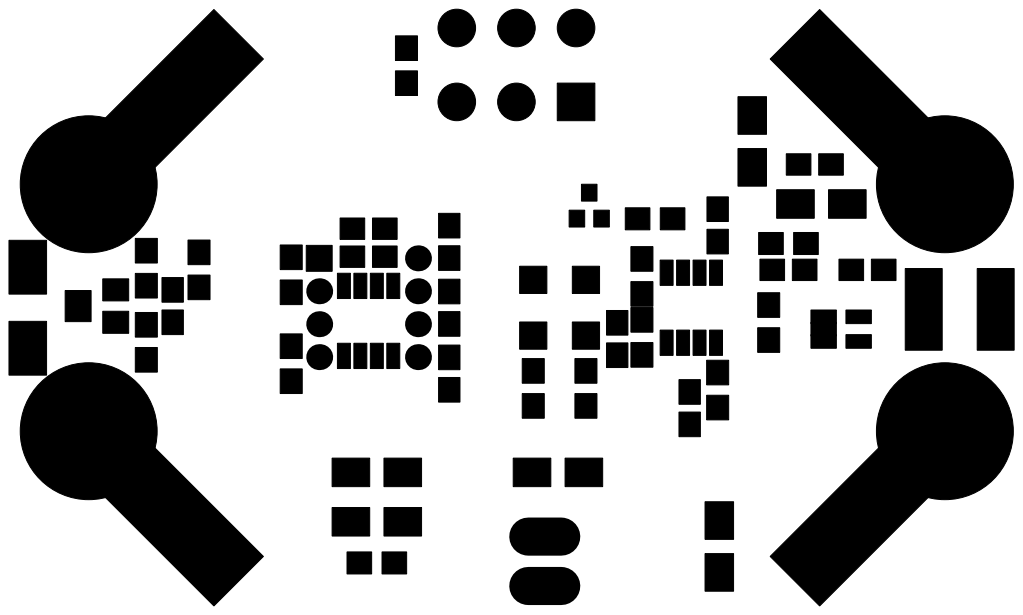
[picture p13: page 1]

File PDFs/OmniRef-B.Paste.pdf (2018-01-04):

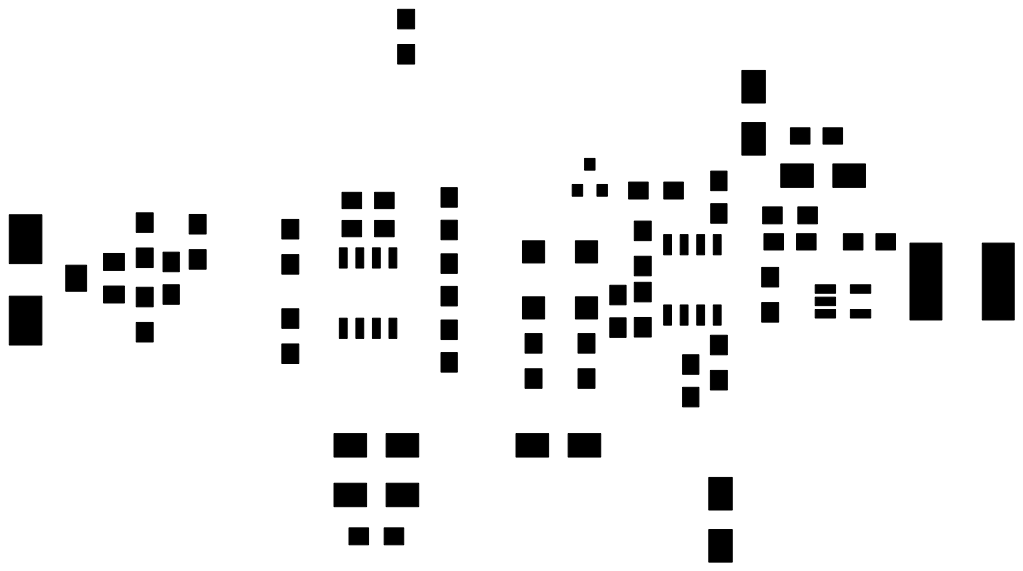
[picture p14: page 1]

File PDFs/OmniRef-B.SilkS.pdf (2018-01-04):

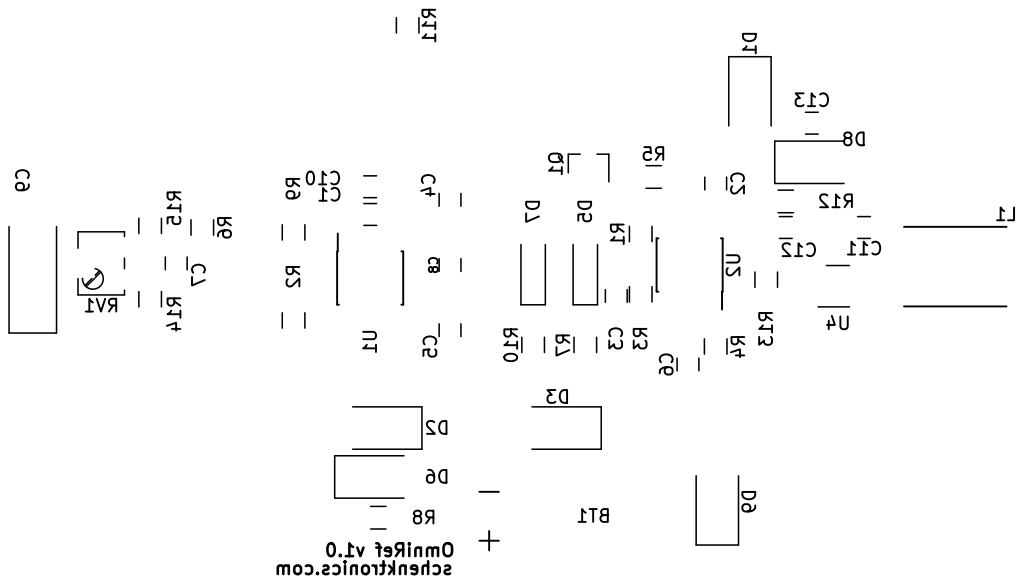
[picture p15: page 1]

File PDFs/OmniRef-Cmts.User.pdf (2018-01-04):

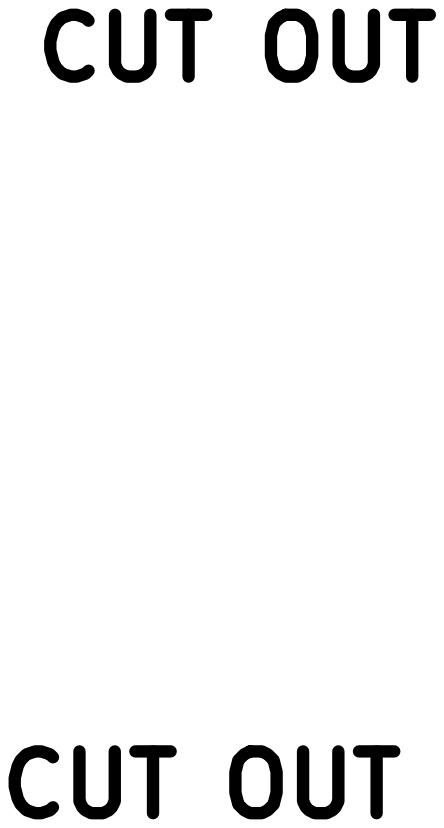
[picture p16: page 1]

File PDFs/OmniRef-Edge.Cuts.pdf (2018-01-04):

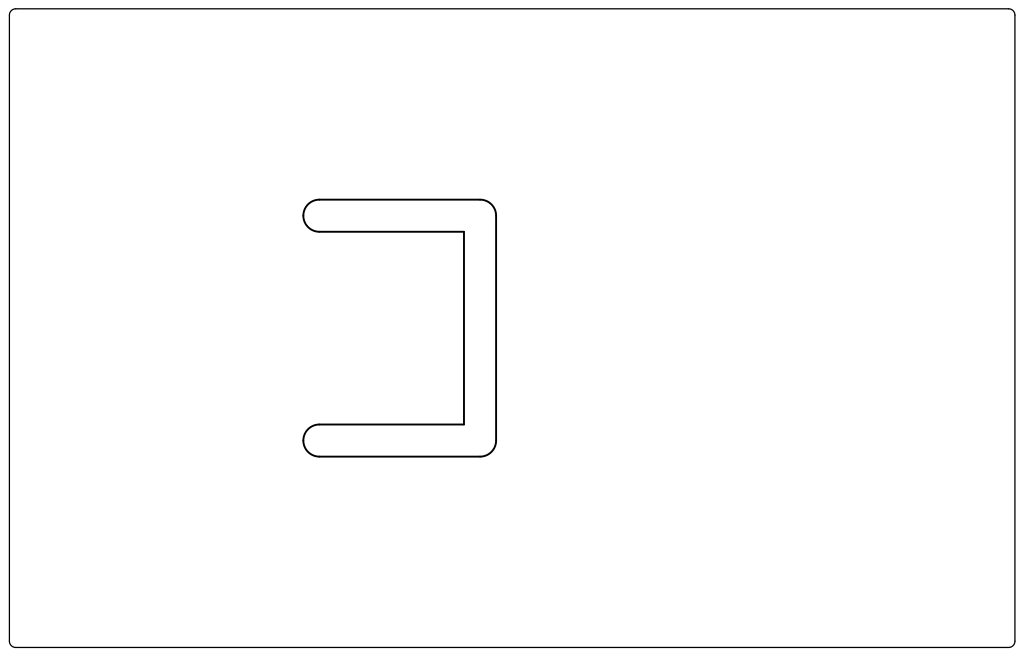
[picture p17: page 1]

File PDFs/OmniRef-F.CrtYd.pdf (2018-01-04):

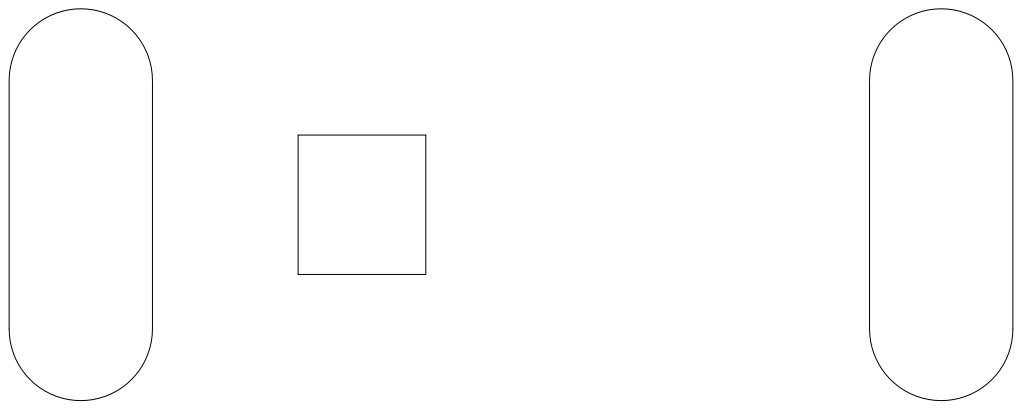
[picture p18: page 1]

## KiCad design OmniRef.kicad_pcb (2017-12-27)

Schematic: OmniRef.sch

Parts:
BT1: Battery; 9vClipWireLeads
C1, C3, C4, C5, C10: 1uF; C_0805_HandSoldering
C2, C6, C7, C8, C11, C13: 10uF; C_0805_HandSoldering
C9: 10uF; CP_Tantalum_Case-C_EIA-6032-28_Hand
C12: 10pF; C_0805_HandSoldering
D1, D2, D3, D9: SMA; D_SMA
D5, D7: LED; LED_1206_2.15mmHole
D6: 12V; D_SMA
D8: D_Schottky; D_SMA
J1: 4mm Banana Jack Pair; Banana_Jack_2pin_Wings_45M_.25_.75
J2: 4mm Banana Jack Pair; Banana_Jack_2pin_Wings_.25_.75
L1: L; Inductor_Taiyo-Yuden_NR-60xx_HandSoldering
Q1: PMBT3906; SOT-23
R1, R8: 10K; R_0805_HandSoldering
R2: 470K; R_0805_HandSoldering
R3, R5: 100K; R_0805_HandSoldering
R4, R6, R9: 1; R_0805_HandSoldering
R7, R10: 3.6K; R_0805_HandSoldering
R11: 0; R_0805_HandSoldering
R12: 1M; R_0805_HandSoldering
R13: 82K; R_0805_HandSoldering
RV1: 10K; Potentiometer_Trimmer_Bourns_3224W
SW1: SW_DPDT_x2; CnK_L_Series_DPDT
U1: REFERENCE IC; SOIC-8_3.9x4.9mm_Pitch1.27mm
U2: LP2951; SOIC-8_3.9x4.9mm_Pitch1.27mm
U3: REFERENCE IC; DIP-8_W7.62mm
U4: AP3015; SOT-23-5_HandSoldering

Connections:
BAT+: C12.1, C13.1, D8.1 (K), R11.1, R12.1, SW1.3
ER: R5.2, U2.5 (~ERROR)
GND: BT1.0, BT1.2 (-), C1.2, C2.2, C4.2, C5.2, C6.2, C8.2, C9.2, C10.2, C11.2, C13.2, D6.2 (A), D9.2 (A), J1.2, J2.2, R1.2, R6.2, R7.2, R8.2, R10.2, R13.2, RV1.1, U1.4 (GND), U2.3 (SHTD), U2.4 (GND), U3.4 (GND), U4.2 (GND)
unnamed: BT1.1 (+), D9.1 (K), R11.2, SW1.6
unnamed: C2.1, D3.1 (K), SW1.2, U2.8 (IN)
unnamed: C3.2, R1.1, R3.2, U2.7 (FEEDBACK)
unnamed: C4.1, U1.8 (NR), U3.8 (NR)
unnamed: C5.1, R2.2, U1.5 (TRIM), U3.5 (TRIM)
unnamed: C6.1, R4.2
unnamed: C7.1, C8.1, C9.1, D2.2 (A), D6.1 (K), J2.1, R8.1, RV1.3, U1.6 (Vout), U3.6 (Vout)
unnamed: C7.2, R6.1
unnamed: C10.1, R9.2, U1.3 (TEMP), U3.3 (TEMP)
unnamed: C11.1, L1.1, SW1.5, U4.4 (~SHTD), U4.5 (IN)
unnamed: C12.2, R12.2, R13.1, U4.3 (FB)
unnamed: D1.1 (K), SW1.1
unnamed: D1.2 (A), J1.1
unnamed: D5.1 (K), R7.1
unnamed: D5.2 (A), Q1.3 (C)
unnamed: D7.1 (K), R10.1
unnamed: D8.2 (A), L1.2, U4.1 (SW)
unnamed: Q1.1 (B), R5.1
unnamed: R2.1, RV1.2
V+: C1.1, C3.1, D2.1 (K), D3.2 (A), D7.2 (A), Q1.2 (E), R3.1, R4.1, R9.1, U1.2 (Vin), U2.1 (OUT), U3.2 (Vin)

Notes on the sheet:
Adjust R1 and R3 values to provide approximately 2v above reference output voltage. With R3 at 100K and R1 at 10K, the voltage should be about 13.58V Adjust R7 and R10 value to light LED with reasonable brightness for the voltage chosen. 3mA seems to be about right for the LED brightness.
R9 is only used for certain Linear Technology IC's. C10 is only used for certain Maxim Integrated IC's. C4 and C5 are optional stability improving capacitors. Check the datasheet of the reference to see if one should be used. R2 and RV1 are to trim the output voltage on certain references.
D6 is intended to clamp the output voltage if driven from an external source. It also provides reverse voltage protection. R8 is to provide a fixed load for the regulator to work against and is probably not needed. Only one output bypass cap is really needed. The different ones shown just provide o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
With R12 at 1M and R13 at 82K, Bat+ should be 16.23V
R11 is only populated if switching stage is not used.

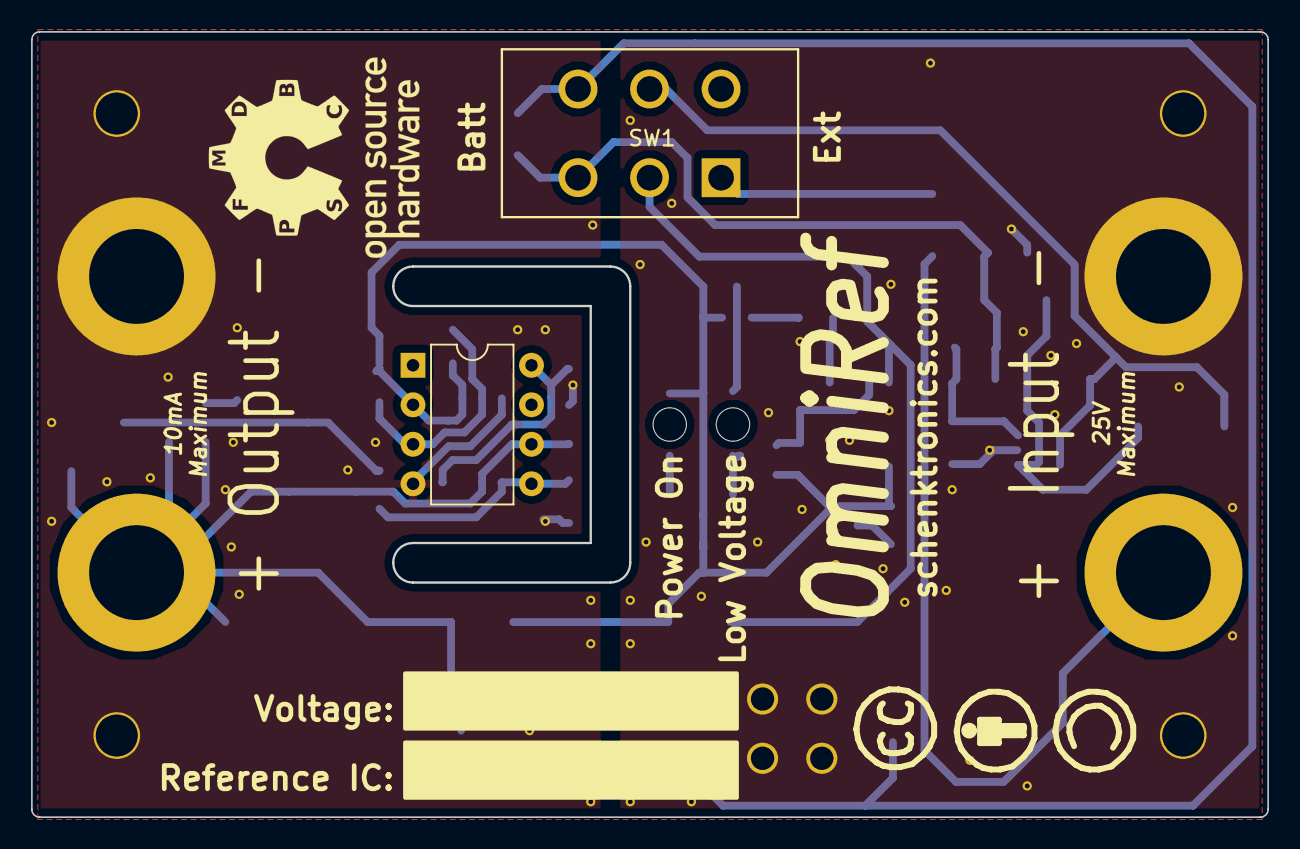
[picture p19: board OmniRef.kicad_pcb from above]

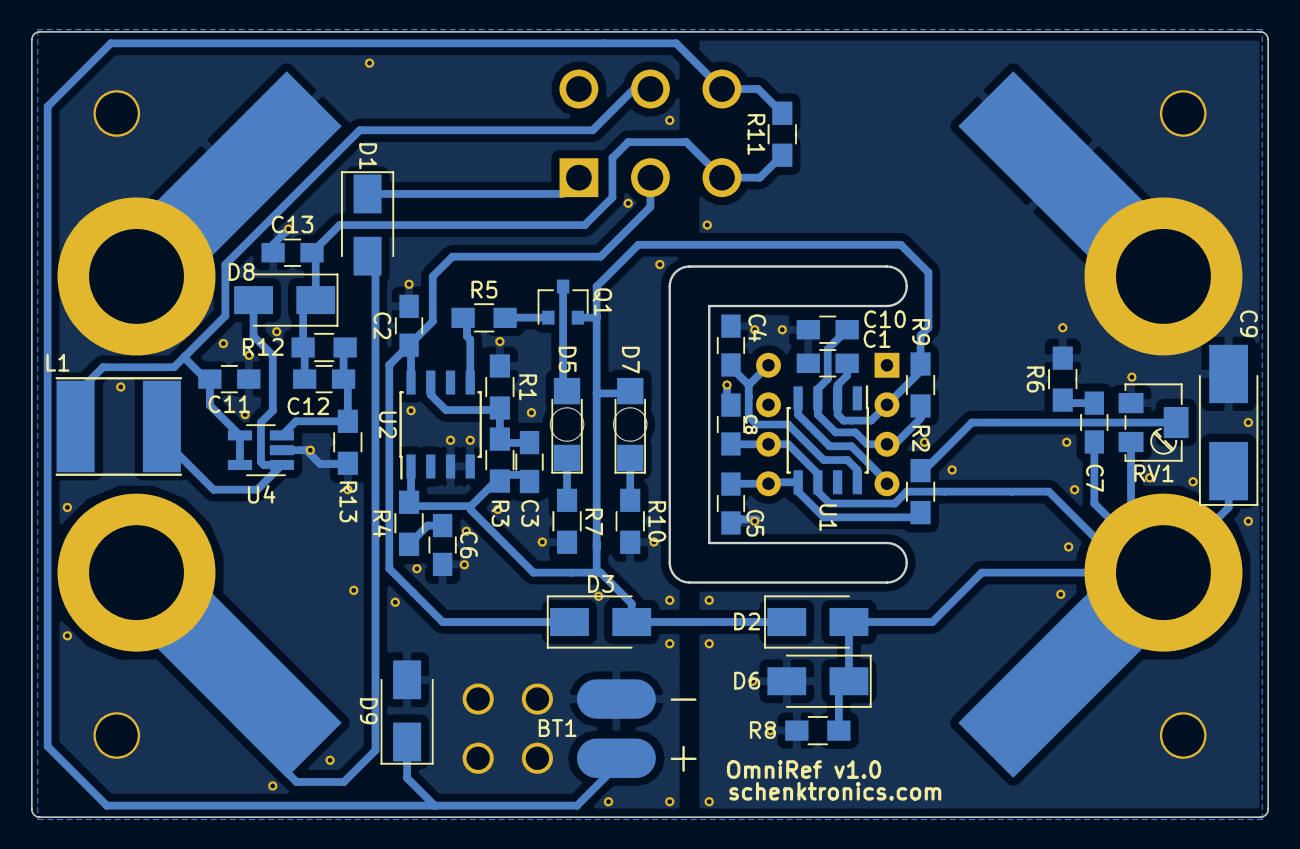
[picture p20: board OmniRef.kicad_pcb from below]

Board: 2 copper layers, 79.5 x 50.5 mm, 45 parts (41 on the bottom side), 23 nets.

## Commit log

2017-12-17 Renamed to OmniRef. Made some final changes to schematic and board before generating gerbers.
    [OmniRef.kicad_pcb, OmniRef.sch]
2017-12-17 Generated Gerbers. Fixed a couple unconnected pads the DRC found.
    [OmniRef-B.Adhes.gbr, OmniRef-B.CrtYd.gbr, OmniRef-B.Cu.gbr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]
2017-12-17 Generated gerber.zip. Ordered prototype boards from seeed.
    [OmniRef.kicad_pcb]
2017-12-19 Added DC-DC converter front end. Adjusted some logos and stuff.
    [OmniRef.kicad_pcb, OmniRef.sch]
2017-12-19 Generated gerbers for new layout.
    [OmniRef-B.Adhes.gbr, OmniRef-B.CrtYd.gbr, OmniRef-B.Cu.gbr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]
2017-12-25 Adjusted size of outline to improve board fit.
    [OmniRef.kicad_pcb, OmniRef.sch, hb1941.dwg]
2017-12-25 Selected resistors for switching regulator. Fixed SW1 wiring.
    [OmniRef.kicad_pcb, OmniRef.sch, Parts Selection.ods]
2017-12-27 Fixed a number of issues discovered during prototyping. Re-arranged logos a bit.
    Moved RV1 between output jacks to clear battery.
    [OmniRef-B.Adhes.gbr, OmniRef-B.CrtYd.gbr, OmniRef-B.Cu.gbr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]
2017-12-27 Adjusted OSHW logo.
    Made PDF's of the schematic and board.
    [OmniRef Parts.ods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]
2017-12-27 Created battery holder and insulator .dxf's for laser cutting.
    1.75mm acrylic sheet worked very well.
    [OmniRef-drl_map.dxf, OmniRef9vGuide.dxf, OmniRefInsulator.dxf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]
2017-12-27 Added holes for potentiometer in insulator plate.
    [OmniRef-B.CrtYd.dxf, OmniRef-Edge.Cuts.dxf, OmniRefInsulator.dxf]
2018-01-04 Added some resistors to "expand the scale" of RV1. Made some other minor modifications.
    Added to the BOM.
    [OmniRef Parts.ods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]
